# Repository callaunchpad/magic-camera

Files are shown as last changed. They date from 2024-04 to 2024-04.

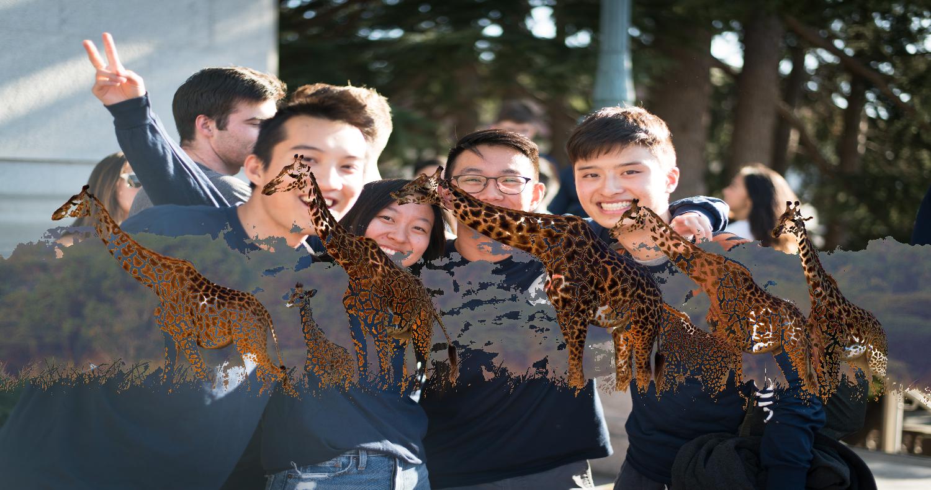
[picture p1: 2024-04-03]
ericasophie/resultimage.jpeg

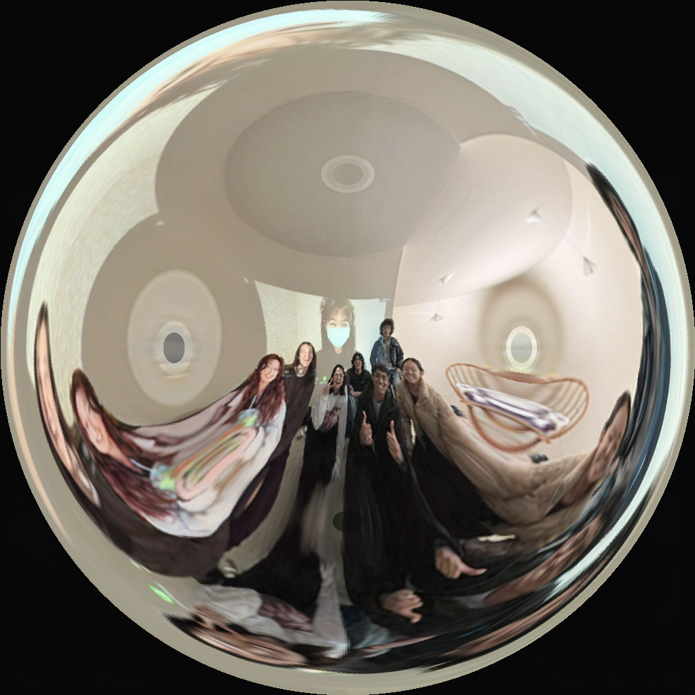
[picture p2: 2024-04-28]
arjun/result.png

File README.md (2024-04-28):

# Magic Camera

## Introduction
Hey! We're Magic Camera!
Screenshot 2024-04-28 at 11 16 54 AM (1)

## features
- **Real-time image processing:** Apply filters and effects as the camera captures video.
- **Customizable Settings:** multiple different modes!

## Prerequisites
To get started with Magic Camera, you will need:
- Python 3.x
ation).

## Installation
Clone this repository to your local system to get started with Magic Camera:
```bash
git clone https://github.com/callaunchpad/magic-camera.git
```
## Usage

Navigate to the project directory and run the following command to start the camera interface:
```bash
python interface/run_display.py
```

## Contributor
Eshaan Moorjani,
Michelle Pan,
Annie Zhang,
Selena Zhao,
Erica Liu,
Arjun Banerjee,
Dhruv Gautam,
Sophie Xie

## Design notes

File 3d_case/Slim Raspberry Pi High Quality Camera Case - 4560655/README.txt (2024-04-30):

Slim Raspberry Pi High Quality Camera Case by sputniC_42 on Thingiverse: https://www.thingiverse.com/thing:4560655

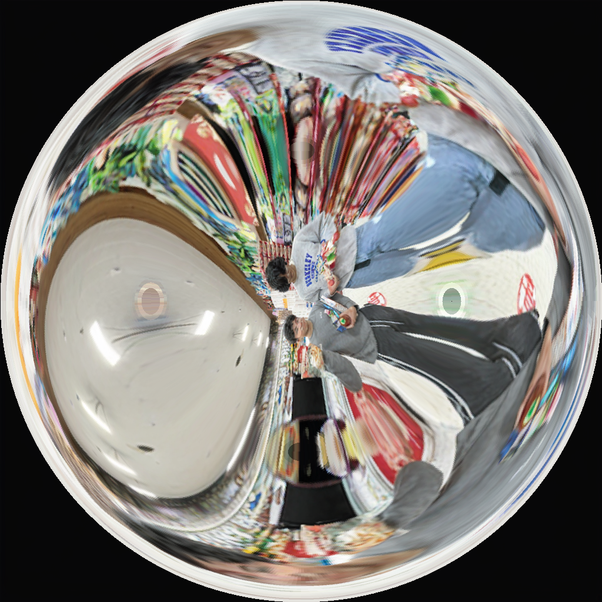
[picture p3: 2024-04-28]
arjun/output.png

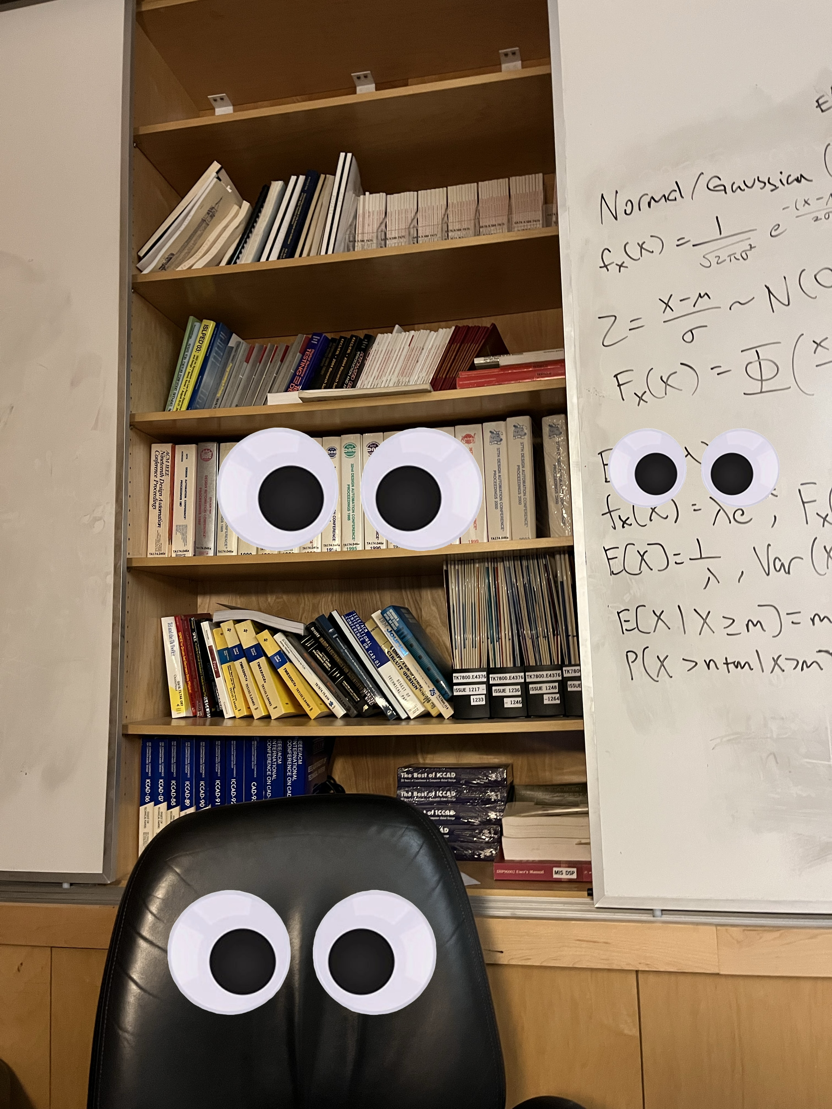
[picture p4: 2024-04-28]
idkwtqo/output.jpg

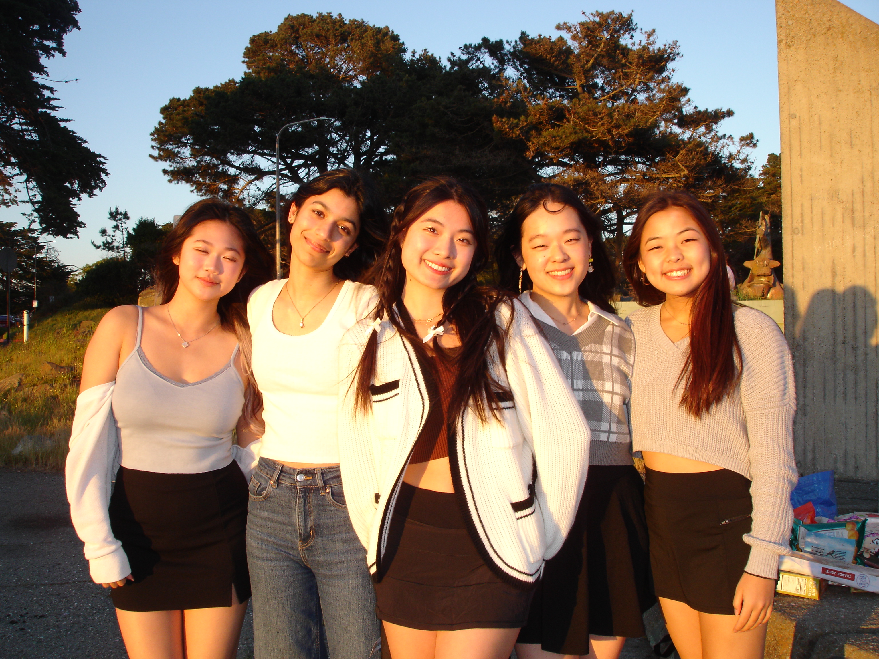
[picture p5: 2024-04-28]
ericaaudio/chrisp.JPG

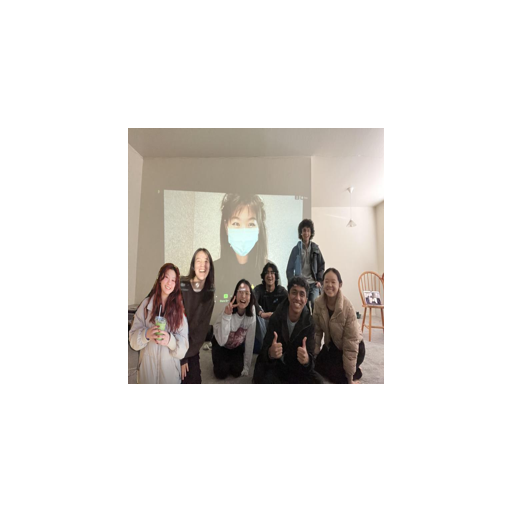
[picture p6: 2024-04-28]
arjun/extended.png

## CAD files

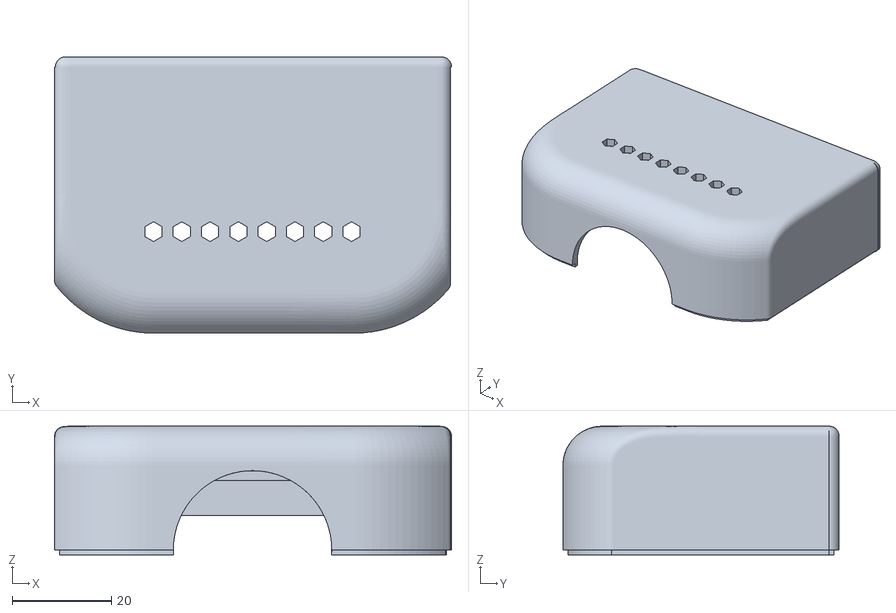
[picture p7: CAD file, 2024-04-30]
3d_case/case_versions/slim rpi top badaboom.stl
80.2 x 55.8 x 26.0

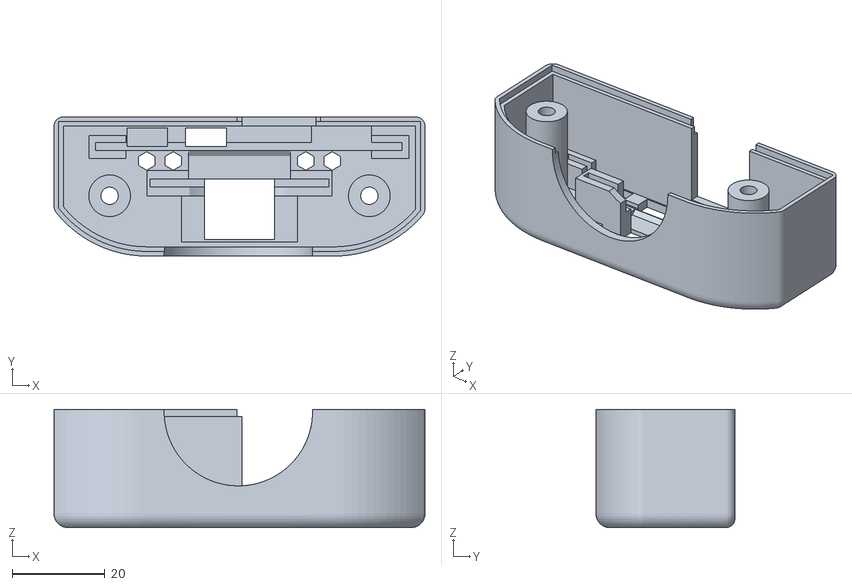
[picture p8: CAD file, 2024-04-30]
3d_case/Slim Raspberry Pi High Quality Camera Case - 4560655/files/PiZeroW_cam_slim_bottom_shell_OTG_only.stl
80.0 x 30.0 x 25.5

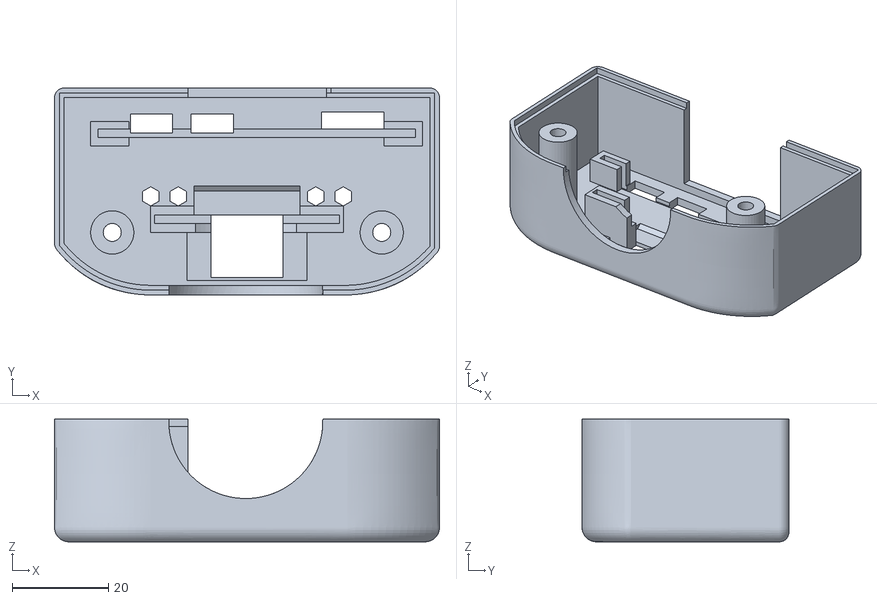
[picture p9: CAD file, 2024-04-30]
3d_case/case_versions/slim rpi case v7.stl
80.0 x 43.0 x 25.5

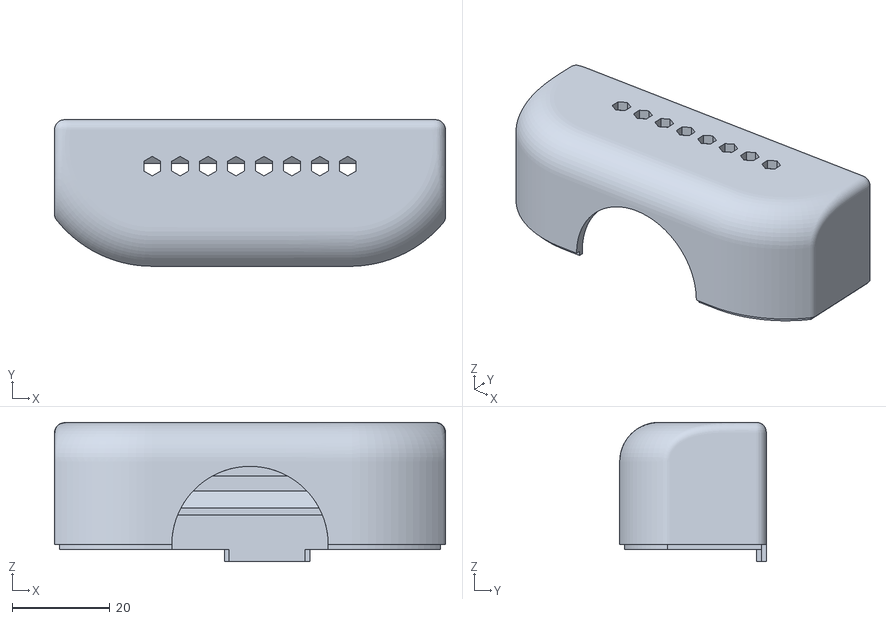
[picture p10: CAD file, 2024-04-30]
3d_case/Slim Raspberry Pi High Quality Camera Case - 4560655/files/PiZero13_cam_slim_top_shell_big_hole.stl
80.0 x 30.0 x 28.5

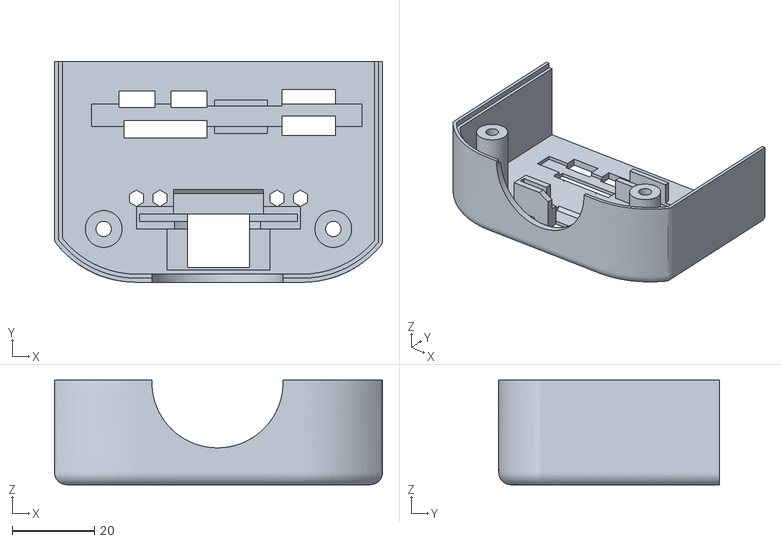
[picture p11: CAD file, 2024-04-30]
3d_case/case_versions/slim rpi case, big screen hole v14.stl
80.0 x 53.8 x 25.5

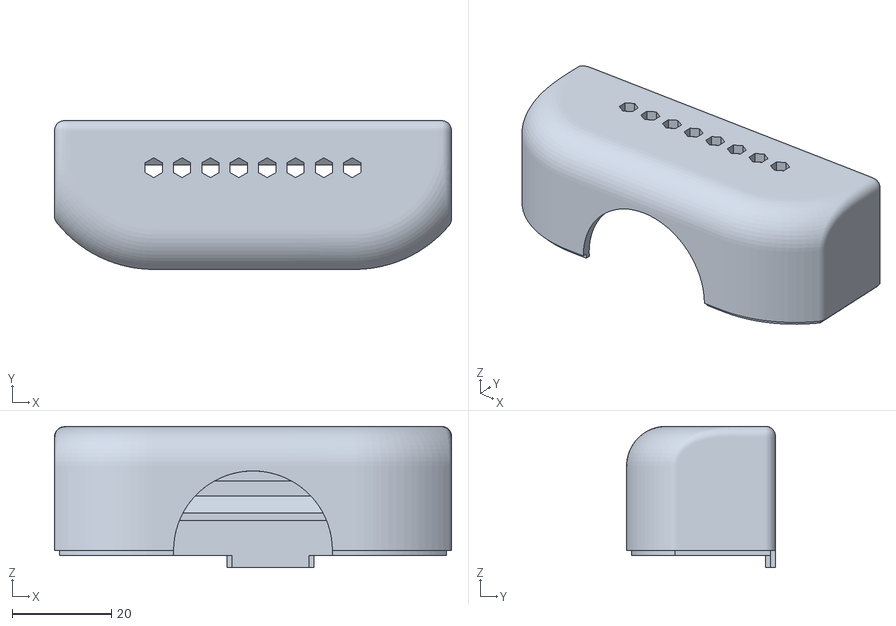
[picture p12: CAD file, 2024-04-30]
3d_case/Slim Raspberry Pi High Quality Camera Case - 4560655/files/PiZero13_cam_slim_top_shell.stl
80.0 x 30.0 x 28.5

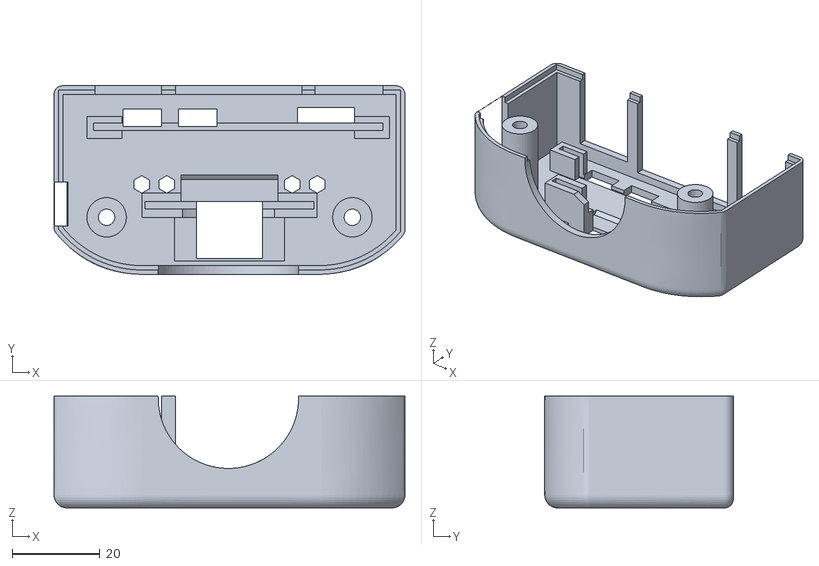
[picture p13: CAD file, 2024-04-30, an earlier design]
3d_case/case_versions/slim rpi case, big screen hole v3.stl
80.0 x 43.0 x 25.5

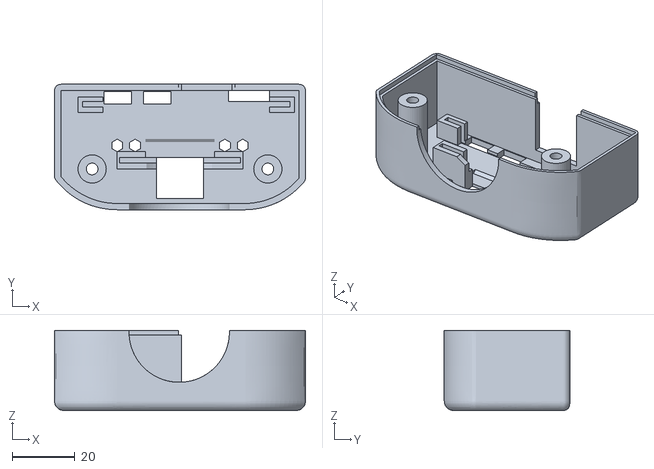
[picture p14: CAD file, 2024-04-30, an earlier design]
3d_case/case_versions/slim rpi case v5.stl
80.0 x 40.0 x 25.5

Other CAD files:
3d_case/case_versions/bottom print with holes v12.stl
3d_case/Slim Raspberry Pi High Quality Camera Case - 4560655/files/PiZero13_cam_slim_bottom_shell_2USB_HDMI_big_hole.stl
3d_case/Slim Raspberry Pi High Quality Camera Case - 4560655/files/PiZeroW_cam_slim_bottom_shell_2USB_HDMI.stl
3d_case/Slim Raspberry Pi High Quality Camera Case - 4560655/files/PiZero13_cam_slim_bottom_shell_2USB_big_hole.stl
3d_case/Slim Raspberry Pi High Quality Camera Case - 4560655/files/PiZero13_cam_slim_bottom_shell_2USB_HDMI.stl
3d_case/Slim Raspberry Pi High Quality Camera Case - 4560655/files/PiZero13_cam_slim_bottom_shell_2USB.stl
3d_case/Slim Raspberry Pi High Quality Camera Case - 4560655/files/PiZero13_cam_slim_bottom_shell_OTG_only_big_hole.stl
3d_case/Slim Raspberry Pi High Quality Camera Case - 4560655/files/PiZeroW_cam_slim_top_shell.stl
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

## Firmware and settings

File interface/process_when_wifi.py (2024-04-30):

import subprocess
import time
import requests
import os
import concurrent.futures
import shutil

BASE_URL = "http://52.25.237.192:8000/"
PROCESS_FILEPATH = 'to_process'

def check_wifi():
    try:
        # On Linux or MacOS, you might use 'ping -c 1 google.com'
        subprocess.check_output(['ping', '-c', '1', 'google.com'])
        return True
    except subprocess.CalledProcessError:
        return False

def perform_api_requests():
    # look at every image in `./to_process` and split it by `_`
    for to_process_filepath in os.listdir(PROCESS_FILEPATH):
        if to_process_filepath.endswith('.png'):
            time_taken, mode_endpoint_name, _ = to_process_filepath.split('_')
            print(f"processing image with mode {mode_endpoint_name}")
            # send image to API
            relative_filepath = os.path.join(PROCESS_FILEPATH, to_process_filepath)
            with open(relative_filepath, "rb") as f:
                files = {"file": f}
                # make this multithreaded so you can do multiple requests at once
                with concurrent.futures.ThreadPoolExecutor(max_workers=5) as executor:
                    future = executor.submit(requests.post, BASE_URL + mode_endpoint_name, files=files)
                    response = future.result()

            shutil.move(relative_filepath, "out")


def main():
    while True:
        if check_wifi():
            print("WiFi is connected, performing API requests...")
            perform_api_requests()
        else:
            print("WiFi not connected, retrying in 120 seconds...")
        time.sleep(120)  # Check every 120 seconds

if __name__ == '__main__':
    main()

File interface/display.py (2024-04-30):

import io
import requests
import time
from enum import Enum
from multiprocessing import Process

import board
from adafruit_rgb_display import st7789
from digitalio import DigitalInOut, Direction
from picamera import PiCamera
from PIL import Image, ImageDraw

from canvas import Canvas
from menu import Menu
from processor import ImageProcessor
from process_when_wifi import check_wifi

BAUDRATE = 24000000
BASE_URL = "http://52.25.237.192:8000/"

class Screen(Enum):
    MENU = 0
    VIEWFINDER = 1
    LOADING = 2
    RESULT = 3


class Display:

    def __init__(self, verbose=False):
        self.verbose = verbose

        cs_pin = DigitalInOut(board.CE0)
        dc_pin = DigitalInOut(board.D25)
        reset_pin = DigitalInOut(board.D24)

        spi = board.SPI()
        disp = st7789.ST7789(
            spi,
            height=240,
            y_offset=80,
            rotation=180,
            cs=cs_pin,
            dc=dc_pin,
            rst=reset_pin,
            baudrate=BAUDRATE,
        )

        backlight = DigitalInOut(board.D26)
        backlight.switch_to_output()
        backlight.value = True

        self.setup_buttons()
        self.canvas = Canvas(disp)
        self.screen = Screen.MENU
        
        mode_dict = self.get_modes()
        mode_names = list(mode_dict.keys())
        self.menu = Menu(self.canvas, mode_names)
        self.processor = ImageProcessor(self.canvas, mode_dict, BASE_URL, verbose=verbose)
        
        self.last_button_press = 0
        self.camera_res = (self.canvas.width, self.canvas.height)
        self.camera_img = None

    def setup_buttons(self):
        self.button_A = DigitalInOut(board.D5)
        self.button_A.direction = Direction.INPUT

        self.button_B = DigitalInOut(board.D6)
        self.button_B.direction = Direction.INPUT

        self.button_L = DigitalInOut(board.D27)
        self.button_L.direction = Direction.INPUT

        self.button_R = DigitalInOut(board.D23)
        self.button_R.direction = Direction.INPUT

        self.button_U = DigitalInOut(board.D17)
        self.button_U.direction = Direction.INPUT

        self.button_D = DigitalInOut(board.D22)
        self.button_D.direction = Direction.INPUT

        self.button_C = DigitalInOut(board.D4)
        self.button_C.direction = Direction.INPUT
    
    def read_buttons(self):
        if time.time() - self.last_button_press < 1.0:
            return

        if not self.button_A.value:
            if self.verbose: print("A pressed")
            if self.screen == Screen.VIEWFINDER:
                self.screen = Screen.MENU
            elif self.screen == Screen.RESULT:
                self.screen = Screen.VIEWFINDER

        elif not self.button_B.value:
            if self.verbose: print("B pressed")
            if self.screen == Screen.MENU:
                self.screen = Screen.VIEWFINDER
            elif self.screen == Screen.VIEWFINDER:
                if self.camera_img is None:
                    print("staying on viewfinder, picture not captured yet")
                else:
                    self.screen = Screen.LOADING # take a picture
            elif self.screen == Screen.RESULT:
                self.screen = Screen.MENU

        elif not self.button_U.value:
            if self.verbose: print("U pressed")
            if self.screen == Screen.MENU:
                self.menu.decrement_mode()

        elif not self.button_D.value:
            if self.verbose: print("D pressed")
            if self.screen == Screen.MENU:
                self.menu.increment_mode()

        else:
            return

        self.last_button_press = time.time()

    # TODO(eshaan): not the best style, fix later
    def _make_request_with_retries_(self, url, max_retries=5, delay=5):
        attempts = max_retries
        while attempts > 0:
            if check_wifi():
                print("wifi is connected")
                try:
                    response = requests.get(url)
                    response.raise_for_status()
                    return response
                except requests.exceptions.RequestException as e:
                    print("request failed, retrying")
            time.sleep(delay)
            attempts -= 1
            return None

    def get_modes(self):
        request_url = BASE_URL + "endpoints"
        response = self._make_request_with_retries_(request_url)
        # response = requests.get(request_url)
        if response and response.status_code == 200:
            modes = response.json()
        else:
            modes = {"StyleBlend": "styleblend",
                "Jimmy-Inator": "jimmyinator",
                "hehe": "hehe",
                "IDKWTQO": "idkwtqo",
                "serica": "serica",
                "StyleSwirl": "sannuv",
                "Eyeful": "eyeful",
                "fAIshbowlML": "fishbowl"}
        if self.verbose:
            print(f"loaded modes: {modes}")
        return modes
      
    def run(self):
        while True:
            if self.screen == Screen.MENU:
                if self.verbose: print("running menu screen")
                self.run_menu()
            elif self.screen == Screen.VIEWFINDER:
                if self.verbose: print("running viewfinder screen")
                self.run_viewfinder()
            elif self.screen == Screen.LOADING:
                if self.verbose: print("running loading screen")
                self.run_loading()
            elif self.screen == Screen.RESULT:
                if self.verbose: print("running result screen")
                self.run_result()

    def run_menu(self):
        while True:
            self.read_buttons()
            if self.screen == Screen.MENU:
                self.menu.draw()
            else:
                return
            
    def run_viewfinder(self):
        self.camera_img = None
        stream = io.BytesIO()
        with PiCamera() as camera:
            camera.framerate = 5
            camera.resolution = (1024, 1024)
            # camera.resolution = self.camera_res
            for _ in camera.capture_continuous(stream, format='jpeg'): 
                self.read_buttons()
                if self.screen == Screen.VIEWFINDER:
                    self.camera_img = Image.open(stream)
                    output_img = self.camera_img.resize([self.camera_res[0], self.camera_res[1]])
                    self.canvas.display_image(output_img)
                    stream.seek(0)
                    stream.truncate()
                else:
                    return
                
    def run_loading(self):
        self.screen = Screen.VIEWFINDER
        self.processor.set_image_target(self.camera_img, self.menu.get_current_mode())
        p1 = Process(
            target=self.processor.process_image,
            args=(self.menu.get_current_mode(),),
        )
        p1.start()
        
        #p2 = Process(target=self.processor.animate_loading)
        #p2.start()
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

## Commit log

2024-03-10 Add OpenCV camera tests
2024-03-18 Add RPi camera test
2024-03-21 Add transparency to camera preview
2024-03-21 Add script to capture image from camera and save it
2024-03-23 Test buttons
2024-03-23 Fix drawing in script
    [menu.py]
2024-03-23 Add text and multiple buttons
2024-04-04 Add image processing flow to interface (#2)
    * Add viewfinder to interface
    * Clean up code
    * oops
    * Actually clean up code
    * Add image processing skeleton
    * Add debugging prints
    * WIP
    * Add Canvas class
    * Add Canvas class
    * oops
    * Fix bugs
    * Add debugging prints
    * Add messages to placeholder screens
    * Prevent screen crashing
    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
    [display.py, image_processor.py, menu.py]
2024-04-04 Finish implementing image processing on camera (#3)
    * Read modes from endpoint
    * Add debugging print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
    [display.py, menu.py, processor.py]
2024-04-28 Fix selected pointer when scrolling
    [menu.py]
2024-04-30 3d case
    [PiZero13_cam_slim_bottom_shell_2USB.stl, PiZero13_cam_slim_bottom_shell_2USB_HDMI.stl, PiZero13_cam_slim_bottom_shell_2USB_HDMI_big_hole.stl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]
2024-04-30 added *experimental* code to process photos when wifi is available (instead of requiring it) & reduced camera frame rate to reduce cpu overheating
    [display.py, process_when_wifi.py, processor.py]
2024-04-30 tested code, works! camera waits till wifi connects successfully to process images
2024-04-30 fixed it so that it moves the image from the processed folder to the out folder
    [process_when_wifi.py]
